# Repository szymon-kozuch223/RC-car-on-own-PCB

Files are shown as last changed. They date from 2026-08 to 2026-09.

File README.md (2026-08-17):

# RC Car — Self-Designed PCB, 3D-Printed
RWD RC car built around my own custom PCB designed in KiCad, including a self-designed step-down converter (LM2596T-based), plus a custom controller, with chassis and remote fully 3D-printed. Communication via nRF24L01, Arduino Nano, 3S Li-ion 18650 power supply.

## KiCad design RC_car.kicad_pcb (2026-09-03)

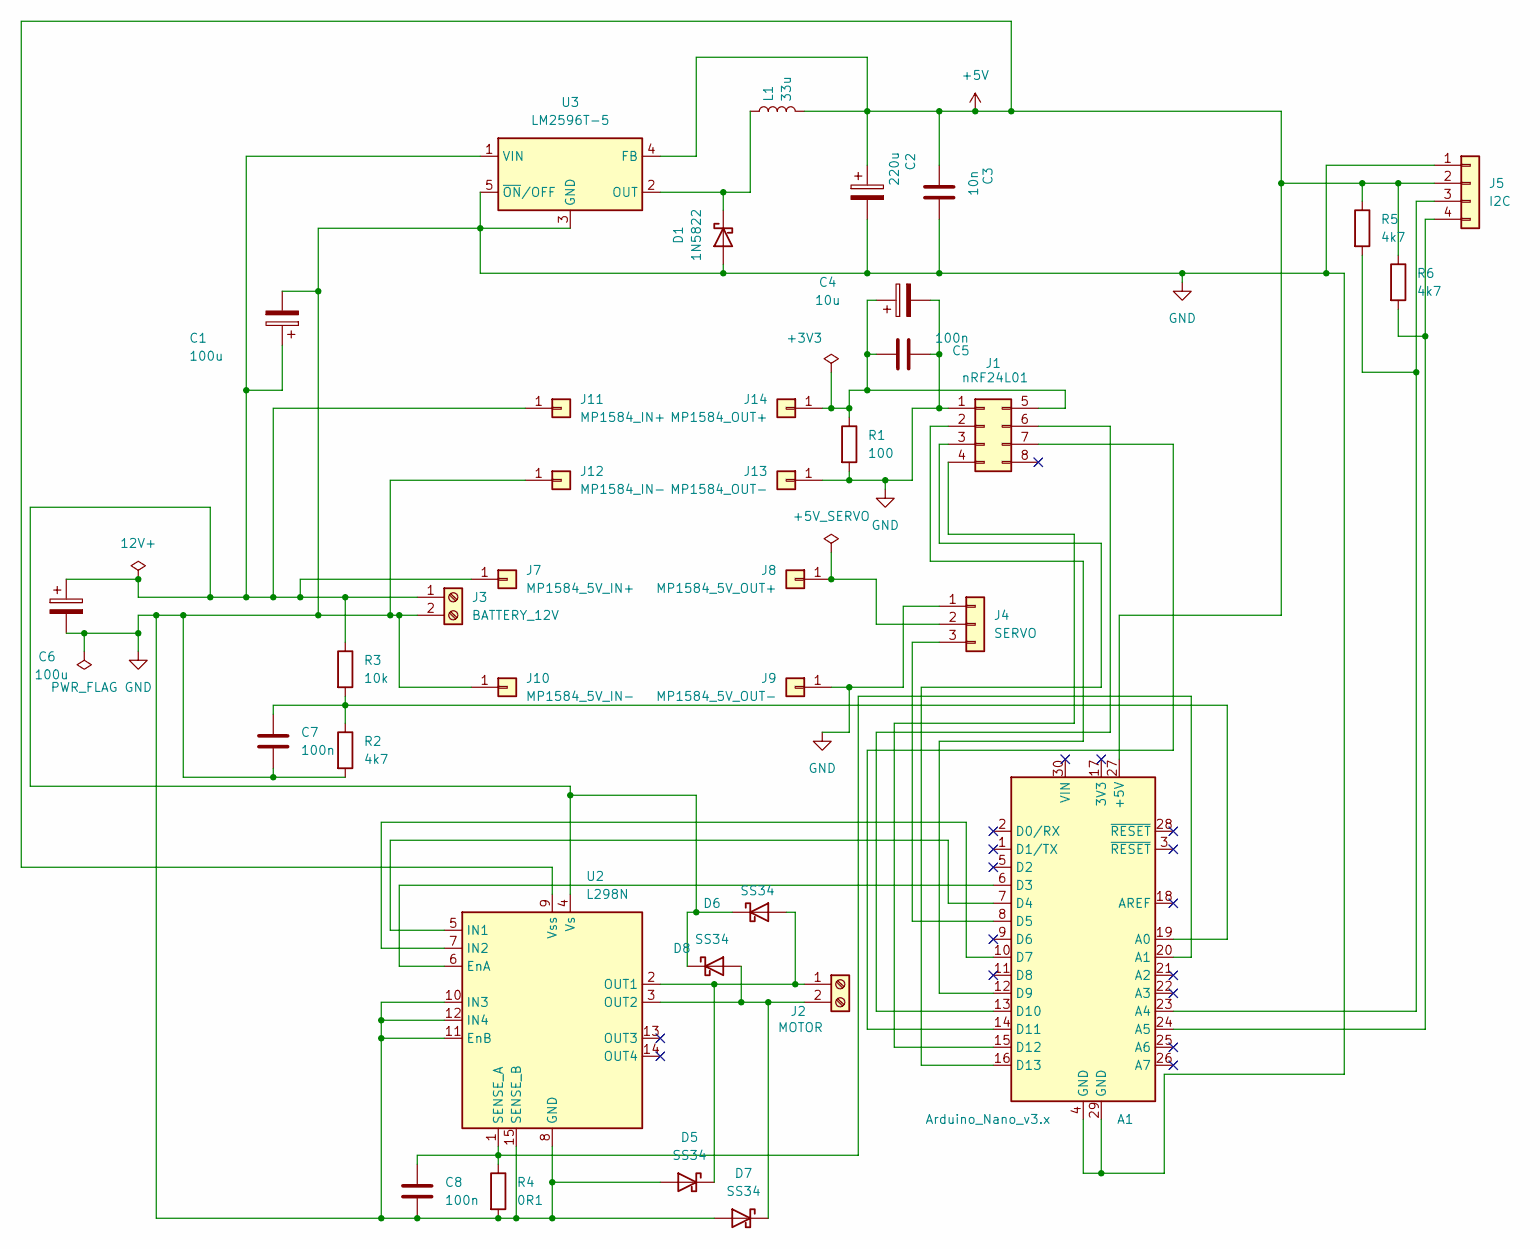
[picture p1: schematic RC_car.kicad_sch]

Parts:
A1: Arduino_Nano_v3.x; Arduino_Nano
C1, C6: 100u; CP_Radial_D8.0mm_P3.50mm
C2: 220u; CP_Radial_D8.0mm_P3.50mm
C3: 10n; C_Disc_D5.0mm_W2.5mm_P5.00mm
C4: 10u; CP_Radial_D8.0mm_P3.50mm
C5, C7, C8: 100n; C_Disc_D5.0mm_W2.5mm_P5.00mm
D1: 1N5822; D_DO-201AD_P15.24mm_Horizontal
D5, D6, D7, D8: SS34; D_DO-201AD_P15.24mm_Horizontal
J1: nRF24L01; PinHeader_2x04_P2.54mm_Vertical
J2: MOTOR; TerminalBlock_RND_205-00001_1x02_P5.00mm_Horizontal
J3: BATTERY_12V; TerminalBlock_RND_205-00001_1x02_P5.00mm_Horizontal
J4: SERVO; PinHeader_1x03_P2.54mm_Vertical
J5: I2C; PinHeader_1x04_P2.54mm_Vertical
J7: MP1584_5V_IN+; PinHeader_1x01_P2.54mm_Vertical
J8: MP1584_5V_OUT+; PinHeader_1x01_P2.54mm_Vertical
J9: MP1584_5V_OUT-; PinHeader_1x01_P2.54mm_Vertical
J10: MP1584_5V_IN-; PinHeader_1x01_P2.54mm_Vertical
J11: MP1584_IN+; PinHeader_1x01_P2.54mm_Vertical
J12: MP1584_IN-; PinHeader_1x01_P2.54mm_Vertical
J13: MP1584_OUT-; PinHeader_1x01_P2.54mm_Vertical
J14: MP1584_OUT+; PinHeader_1x01_P2.54mm_Vertical
L1: 33u; L_Radial_D8.7mm_P5.00mm_Fastron_07HCP
R1: 100; R_Axial_DIN0207_L6.3mm_D2.5mm_P10.16mm_Horizontal
R2, R5, R6: 4k7; R_Axial_DIN0207_L6.3mm_D2.5mm_P10.16mm_Horizontal
R3: 10k; R_Axial_DIN0207_L6.3mm_D2.5mm_P10.16mm_Horizontal
R4: 0R1; R_Axial_DIN0207_L6.3mm_D2.5mm_P10.16mm_Horizontal
U2: L298N; TO-220-15_P2.54x5.08mm_StaggerOdd_Lead4.58mm_Vertical
U3: LM2596T-5; TO-220-5_P3.4x3.7mm_StaggerEven_Lead3.8mm_Vertical

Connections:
+5V: A1.27 (+5V), C2.1, C3.1, J5.2, L1.2, R5.1, R6.1, U2.9 (Vss), U3.4 (FB)
GND: A1.4 (GND), A1.29 (GND), C1.2, C2.2, C3.2, C4.2, C5.1, C6.2, C7.2, C8.2, D1.2 (A), D5.2 (A), D7.2 (A), J1.1 (Pin_a1), J3.2, J4.1, J5.1, J9.1 (Pin_1_1), J10.1 (Pin_1_1), J12.1 (Pin_1_1), J13.1 (Pin_1_1), R1.2, R2.2, R4.2, U2.8 (GND), U2.10 (IN3), U2.11 (EnB), U2.12 (IN4), U2.15 (SENSE_B), U3.3 (GND), U3.5 (~ON/OFF)
unnamed: A1.19 (A0), C7.1, R2.1, R3.2
unnamed: A1.20 (A1), C8.1, R4.1, U2.1 (SENSE_A)
unnamed: A1.23 (A4), J5.3, R5.2
unnamed: A1.24 (A5), J5.4, R6.2
unnamed: A1.6 (D3), U2.6 (EnA)
unnamed: A1.7 (D4), U2.5 (IN1)
unnamed: A1.8 (D5), J4.3
unnamed: A1.10 (D7), U2.7 (IN2)
unnamed: A1.12 (D9), J1.2 (Pin_a2)
unnamed: A1.13 (D10), J1.6 (Pin_b2)
unnamed: A1.14 (D11), J1.7 (Pin_b3)
unnamed: A1.15 (D12), J1.4 (Pin_a4)
unnamed: A1.16 (D13), J1.3 (Pin_a3)
unnamed: D1.1 (K), L1.1, U3.2 (OUT)
unnamed: D5.1 (K), D6.2 (A), J2.1, U2.2 (OUT1)
unnamed: C1.1, C6.1, D6.1 (K), D8.1 (K), J3.1, J7.1 (Pin_1_1), J11.1 (Pin_1_1), R3.1, U2.4 (Vs), U3.1 (VIN)
unnamed: D7.1 (K), D8.2 (A), J2.2, U2.3 (OUT2)
unnamed: C4.1, C5.2, J1.5 (Pin_b1), J14.1 (Pin_1_1), R1.1
unnamed: J4.2, J8.1 (Pin_1_1)

Board: 2 copper layers, 36 parts (0 on the bottom side), 21 nets, no tracks yet.

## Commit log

2026-08-17 Add KiCad schematic
    Including: power suply, L298N, nRF24L01, sevo, battery voltage monitoring, 2 step-downs and one self designed (LM2596T-based)
    [RC_car.kicad_sch]
2026-08-19 Fixed diodes orientation, rework grounding
    - reversed all 4 SS34 flyback diodes on L298N outputs
    - Nano now powered via 5V pin instead of VIN
    - unified ground islands with power:GND symbols
    [RC_car.kicad_sch]
2026-08-20 Remove KiCad lock file
2026-08-20 Improve schematic readability
    [RC_car.kicad_sch]
2026-08-22 Assign preliminary footprints to all components
    Preliminary — to be verified against physical parts after delivery:
    - L1 (33uH inductor): diameter and lead pitch
    - C1, C2, C6 (electrolytics): diameter and pitch
    - J2, J3 (screw terminals): pitch (assumed 5.08mm)
    [RC_car.kicad_sch]
2026-08-30 Change footprints J2/J3 to TerminalBlock_ARK-2P_P5.00mm
    [RC_car.kicad_sch]
2026-08-30 Add .gitignore for KiCad temp files
2026-09-03 Fix footprint names for R1-R6, L1, U3, J2, J3, J1 pin mapping
    [RC_car.kicad_pcb, RC_car.kicad_sch]
2026-09-07 PCB placement: power/logic zone separation, beta vision of the pcb layout
2026-09-11 PCB routing: power rails and I2C/signal traces
2026-10-16 Add RC_car_opt: ground-up optimised PCB layout
    Same schematic/netlist and same 90x70 mm board outline as RC_car;
    placement and routing rebuilt from scratch in a separate project so
    the existing RC_car files are untouched.
    - zoned floorplan: battery/motor + L298N left, LM2596 buck bottom-left,
    Nano centre, nRF24 top-right far from both switchers
    - flyback pairs D5/D6 and D7/D8 sit directly on their OUT1/OUT2 nodes
    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
2026-10-18 Add RC_car_v2: 100x70 board with real MP1584 module footprints
    Third layout, separate project again - RC_car and RC_car_opt untouched.
    Netlist identical to the schematic (verified pad-by-pad).
    Why: the MP1584 pad pitch inherited from RC_car (11.5 x 5.0/5.5 mm) does
    not match the real module. Measured off the product photo it is about
    17.9 x 12.2 mm, so neither RC_car nor RC_car_opt could ever have accepted
    these modules. Both module instances also disagreed with each other.
    - board grown to 100 x 70 mm to make room for two 22.5 x 17 mm modules
    - module pads: 4 outer holes per module, 1.5 mm drill, 2.8 x 4.7 mm oval
    pads offset toward the pair partner so solder bridges the slop
    - module b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
